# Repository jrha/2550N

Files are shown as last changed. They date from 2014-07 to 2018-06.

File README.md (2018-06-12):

2550N
=====

50W Silver Jubilee Clone with independent gain controls.

Schematics and layouts developed with [KiCad](http://www.kicad-pcb.org).

Inspired by [SDM's Jubilee layouts](https://web.archive.org/web/20151026191650/http://home.comcast.net/~mamp17/Jubilee%20Layouts.html) with redrawn schematics for layout, part reference and BOM purposes.

Actual physical layouts are **very** specific to the chassis and parts I used and should be treated as a reference only.

If in doubt, follow [SDM's Jubilee layouts](https://web.archive.org/web/20151026191650/http://home.comcast.net/~mamp17/Jubilee%20Layouts.html) which are proven by many other builders!

Also see [original schematics](https://github.com/a-wai/ampfactory/blob/ba2dfc92f6a288e0c178695ec74adb9c7a02d9bf/non-free/Marshall/Silver%20Jubilee/Silver%20Jubilee%20-%202550.pdf) for reference.

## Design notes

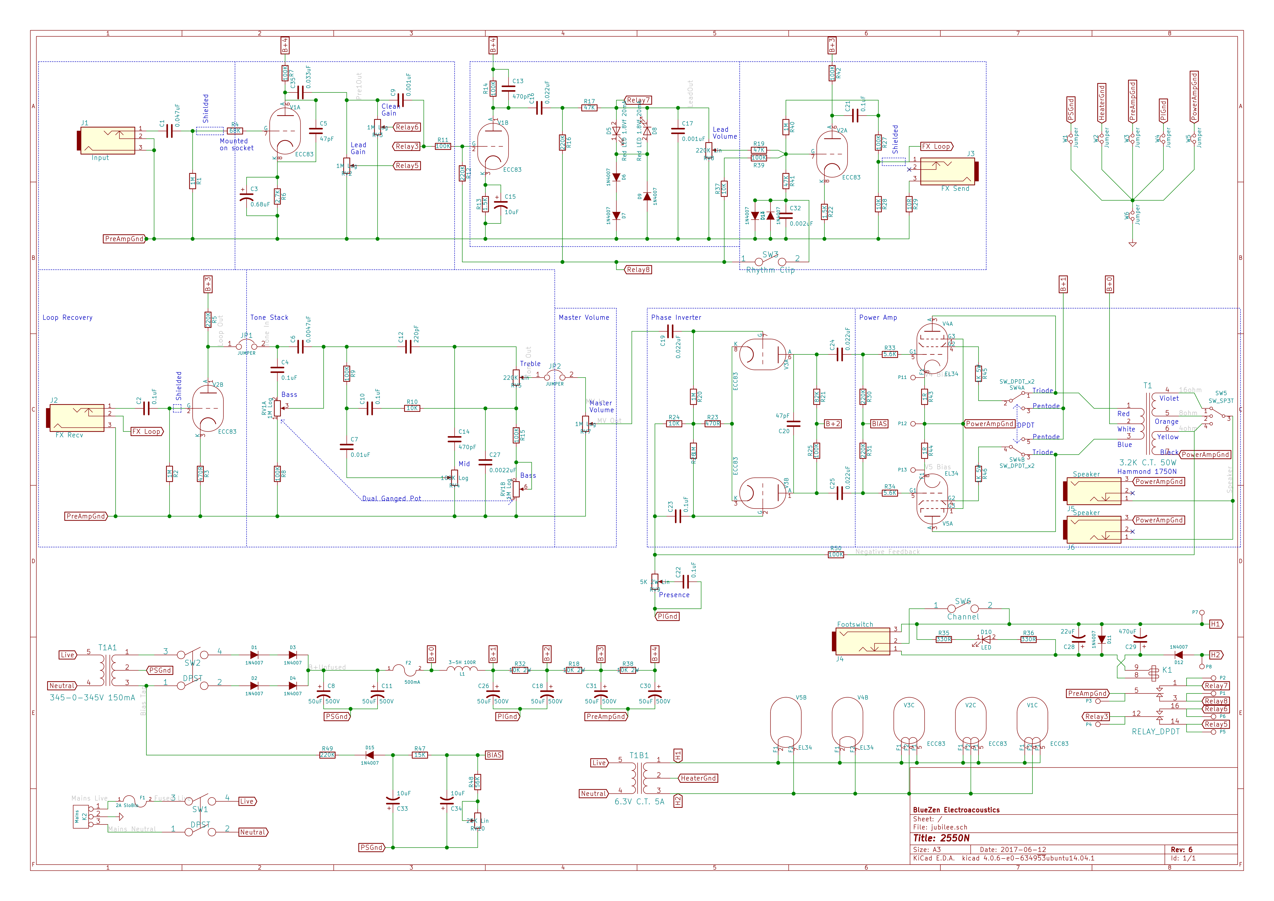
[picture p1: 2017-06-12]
build/schematic.png

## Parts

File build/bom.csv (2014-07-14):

Qty | Reference(s) | Value
1 | C1 | 0.047uF
6 | C10, C2, C21, C22, C23, C4 | 0.1uF
6 | C11, C18, C26, C30, C31, C8 | 50uF 500V
1 | C12 | 220pF
2 | C13, C14 | 470pF
3 | C15, C33, C34 | 10uF
4 | C16, C19, C24, C25 | 0.022uF
2 | C17, C9 | 0.001uF
2 | C20, C5 | 47pF
1 | C27 | 0.0022uF
1 | C28 | 22uF
1 | C29 | 470uF
1 | C3 | 0.68uF
1 | C32 | 0.002uF
1 | C35 | 0.033uF
1 | C6 | 0.0047uF
1 | C7 | 0.01uF
12 | D1, D11, D12, D13, D14, D15, D2, D3, D4, D6, D7, D9 | 1N4007
1 | D10 | LED
2 | D5, D8 | Red LED 1.8Vf 20mA
1 | F1 | 2A SloBlo
1 | F2 | 500mA
4 | J1, J4, J5, J6 | JACK_2P
1 | J2 | FX Recv
1 | J3 | FX Send
2 | JP1, JP2 | JUMPER
1 | K1 | RELAY_DPDT
1 | K2 | Mains
1 | L1 | 3-5H 100R
11 | P1, P11, P12, P13, P2, P3, P4, P5, P6, P7, P8 | CONN_1
1 | P9 | CONN_4
5 | R1, R2, R20, R26, R40 | 1M
4 | R10, R24, R28, R37 | 10K
11 | R11, R14, R15, R25, R27, R39, R42, R50, R7, R8, R9 | 100K
6 | R12, R16, R30, R31, R49, R5 | 220K
2 | R13, R22 | 1.5K
3 | R17, R19, R41 | 47K
3 | R18, R32, R38 | 10K 2W
1 | R21 | 82K
2 | R23, R3 | 470R
1 | R29 | 10R
2 | R33, R34 | 5.6K
2 | R35, R36 | 330R
1 | R4 | 68K
2 | R43, R44 | 1R
2 | R45, R46 | 1K 5W
1 | R47 | 15K
1 | R48 | 56K
1 | R6 | 2.7K
5 | RV1, RV2, RV3, RV6, RV7 | 1M Log
1 | RV10 | 25K Lin
1 | RV4 | 100K Log
2 | RV5, RV8 | 220K Lin
1 | RV9 | 5K 2W Lin
2 | SW1, SW2 | DPST
2 | SW3, SW6 | SPST
2 | SW4, SW5 | SPDT
1 | T1 | 3.2K C.T. 50W
1 | T1A1 | 345-0-345V 150mA
1 | T1B1 | 6.3V C.T. 5A
3 | V1, V2, V3 | ECC83
2 | V4, V5 | EL34
6 | W1, W2, W3, W4, W5, W6 | TEST

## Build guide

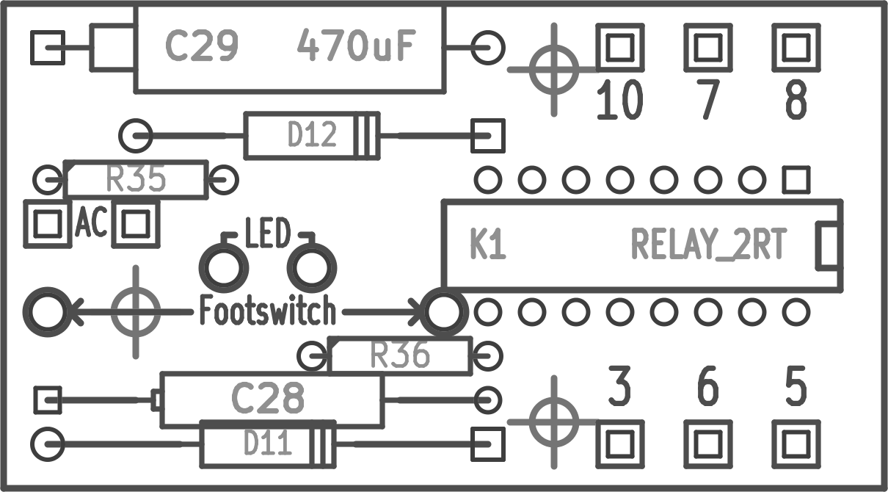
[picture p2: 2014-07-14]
build/board-footswitch.png

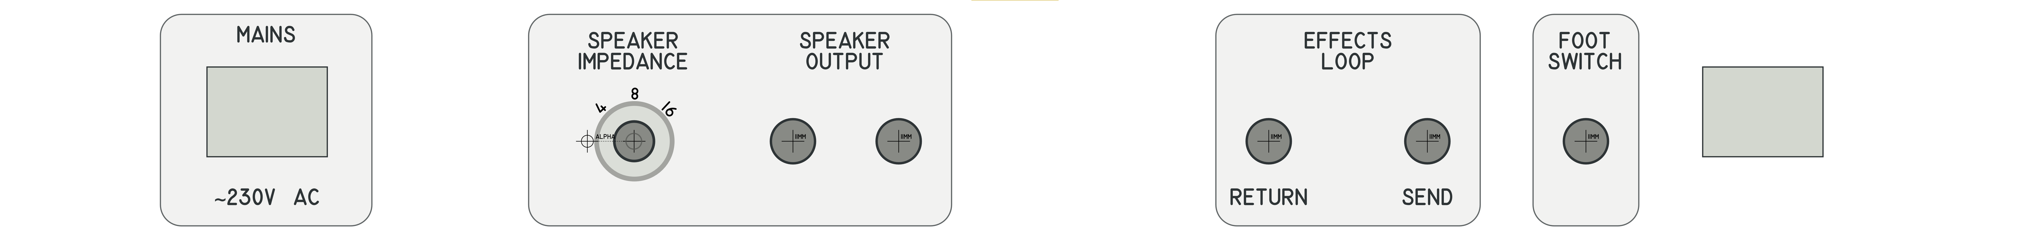
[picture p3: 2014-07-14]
build/layout-rear.png

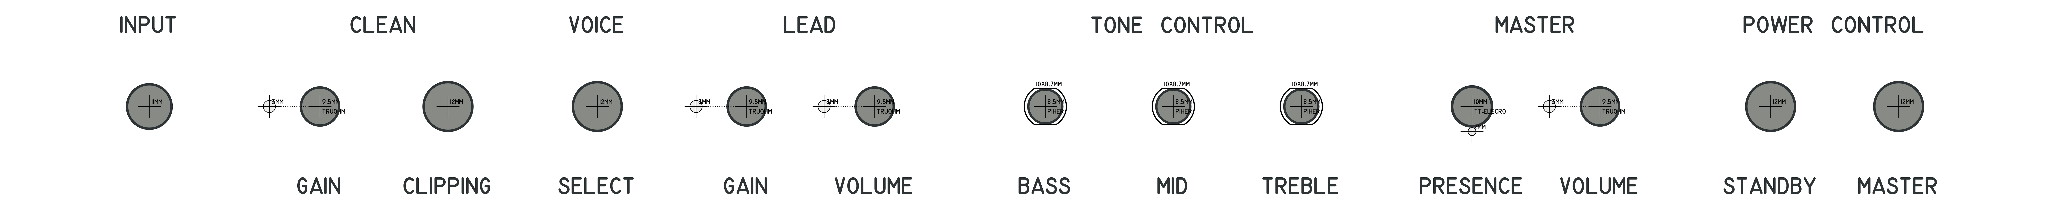
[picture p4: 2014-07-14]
build/layout-front.png

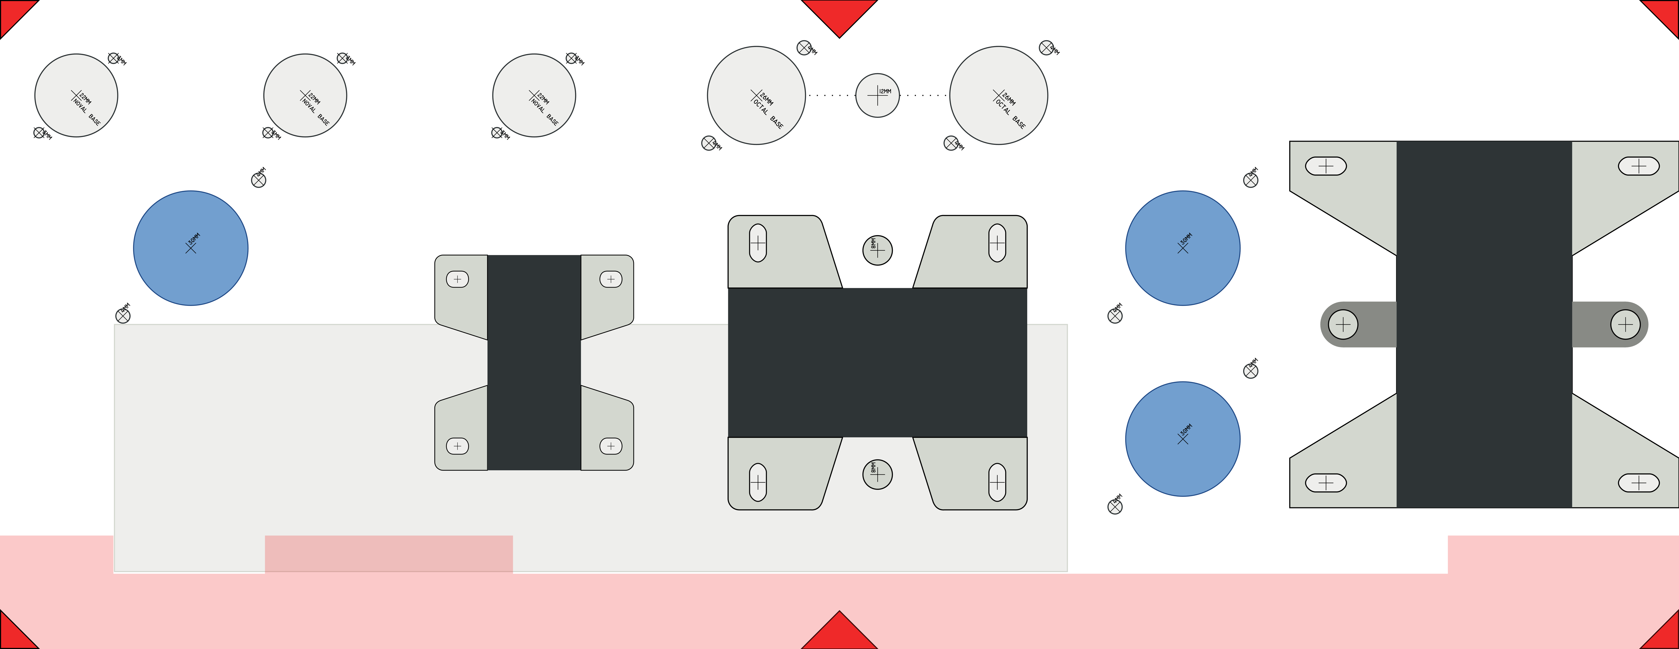
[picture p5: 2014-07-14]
build/layout-top.png

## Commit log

2014-07-13 Add revision 4 schema after KiCad upgrade
    [jubilee.sch]
2014-07-13 Bump issue date to reflect schema revision
    [jubilee.sch]
2014-07-14 Add pre-upgrade board layout
    This is just for reference to preserve the layout before the kicad upgrade.
    The only useful part of the layout are the footswitch and turret board layouts, the rest is messy crap.
    [jubilee.brd]
2014-07-14 Add build directory with layout images
    These are **very** specific to the chassis and components used for my build,
    but are a useful reference anyway.
    TODO: Include SVG sources.
2014-07-14 Add BOM generated from netlist
    This is very much a first pass and needs cleanup, but appears to be correct.
    [bom.csv]
2014-07-14 Add BOM generation scripts from KiCad source tree
    bom_maker.py is a fork of bom_csv_grouped_by_value.py
2014-07-14 Do not print list of individual components
    We're only interested in the collated list.
2014-07-14 Drop item column
    We're only intrested in the component references.
    [bom.csv]
2014-07-14 Correct typos in components values for two resistors
    Formatting only.
    [jubilee.sch]
2014-07-14 Switch back to `csv` module's writerow
    We don't need utf-8 and we want it's more intelligent quoting rules.
2014-07-14 Update BOM with fixed values from schema
    This correctly groups the errant resistors and fixes the quantity values.
    [bom.csv]
2014-07-14 Add PNG copy of schematic
    TODO: Fix problems with SVG output and publish schematic in SVG.
2014-07-14 Clarify order of heater connections and bump revision
    The previous layout was correct in netlist terms, but the schematic gave the impression that the ECC83 heaters should be connected first and the EL34 heaters last, when in fact the opposite is true.
    [jubilee.sch]
2014-07-14 Add link to 2550 original schematics from a-wai/ampfactory
2014-07-20 Add notes to indicate shielded wire connections
    Also add missing "do not connect" flags on speaker jacks.
    [jubilee.sch]
2014-07-20 Use value fields of jacks and switches consistently
    They are now all labels indicating their purpose.
    [jubilee.sch]
2014-07-20 Spell rhythm correctly
    ¬_¬
    [jubilee.sch]
2014-08-16 Correct channel connections on relay and label wire colours on OT
    [jubilee.sch]
2017-06-12 Update for compatability with latest KiCad
    Switch to appropriate symbols from newer libraries.
    [jubilee.sch]
2018-06-12 Restructure and add licensing information
    Code is licensed under GPL-2.0.
    Schematics, layouts and images are licensed under CC-BY-SA-4.0.
    [bom.csv, jubilee.brd, jubilee.sch]
